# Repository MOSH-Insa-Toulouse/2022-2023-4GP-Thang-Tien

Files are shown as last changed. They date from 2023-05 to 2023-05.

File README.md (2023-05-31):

# 2022-2023-4GP-Thang-Tien

# 1. Contexte et objectifs du projet
- [x] Réaliser une jauge de contrainte low-tech à base de graphite: [Pencil Drawn Strain Gauges and Chemiresistors on Paper](https://www.researchgate.net/publication/259846610_Pencil_Drawn_Strain_Gauges_and_Chemiresistors_on_Paper)
- [x] Concevoir un shield Arduino contenant l'amplificateur du capteur et les composants électroniques annexes (émetteur/récepteur Bluetooth, encodeur rotatif et écran OLED)
- [x] Réaliser une application mobile connectée à l'émetteur Bluetooth du capteur sous APP MIT INVENTOR 
- [x] Effectuer une évaluation du capteur sur un banc d'essai afin de produire une fiche technique et de comparer la technologie utilisée avec celle d'un autre capteur commercial similaire

# 2. Capteur de contrainte
> Notre capteur de contrainte utilise une jauge en papier équipée d'un circuit résistif en graphite, offrant l'avantage d'être facile à installer à moindre coût.
> La théorie de la percolation est exploitée dans ce capteur low-tech, qui est composé de nanoparticules de graphite formant des feuillets. Le réseau percolé caractéristique de la fine couche de graphite déposée sur la feuille de papier permet le transport des électrons entre les nanoparticules par l'effet tunnel. La déformation de la jauge en tension ou en compression entraîne une variation de la résistance de la couche de graphite, ce qui permet de mesurer la contrainte et la déformation appliquées.
> Le fonctionnement de notre jauge de contrainte repose sur la variation de la résistance du circuit résistif en fonction de sa déformation. Elle est alimentée par une tension régulée de 5V fournie par une carte Arduino UNO. Le courant circulant dans la jauge est mesuré pour fournir le signal du capteur, qui doit ensuite être amplifié et filtré.
  ## 2.1. Circuit amplificateur
  > La conductance des jauges en graphite que nous utilisons est très faible (de l'ordre de la dizaine de nS) et est alimentée par une tension continue de 5V. Le circuit amplificateur du capteur doit alors être en mesure d'extraire l'information d'un signal en courant de très faible intensité.
 > Dans ce projet, nous avons décidé d'utiliser un montage transimpédance constitué d'un amplificateur opérationnel (AOP) pour fournir un signal en tension suffisant au convertisseur analogique-numérique (ADC) d'une carte Arduino UNO.
 
 >   Notre jauge de contrainte est composée d'une seule résistance en série. De ce fait, notre signal est sensible aux dérives en tension de l'amplificateur. Notre AOP doit donc avoir un offset de tension en entrée très faible de manière à ce qu'il ne puisse fausser le signal fourni à l'ADC. Cela restreint notre choix d'amplificateur opérationnel. Nos jauges de contrainte en graphite ont une conductivité aux alentours de 10 nS. La jauge étant alimentée par 5V, nous nous attendons à avoir un signal en courant de l'ordre de 50 nA. En shuntant ce courant par une résistance de 100 kΩ, le signal en tension fourni à l'AOP est de 5 mV. À titre de comparaison, l'amplificateur [LM741](https://www.ti.com/lit/ds/symlink/lm741.pdf) présente un offset en entrée typique de 1 mV, et pouvant atteindre 5 mV. Ce composant n'est donc pas adapté pour notre utilisation. Ainsi notre amplificateur doit spécifiquement présenter un offset en entrée faible. Pour cette raison, nous utilisons le [LTC1050](https://www.analog.com/media/en/technical-documentation/data-sheets/1050fb.pdf), pour sa tension de dérive de 5 µV, soit 1000 fois plus faible que notre signal nominal de 5 mV.
 
 >   À partir de cet AOP, nous élaborons l'architecture du circuit amplificateur (cf. [Figure 1a](analog_circuit_images/analog_circuit.JPG)). Ce dernier dispose de trois étages de filtrage:
 >   - à l'entrée, un filtre passe-bas (R1C1) de fréquence de coupure de 16 Hz permet de filtrer les bruits en courant sur le signal d'entrée
 >   - un autre filtre passe bas de 1.6 Hz (R3C2) couplé à l'AOP permet de filtrer la composante du bruit à 50 Hz provenant du réseau électrique
 >   - à la sortie de l'amplificateur, un dernier filtre (R4C4) de 1.6 kHz permet de traiter les bruits dus à l'échantillonage de l'ADC

 >   La capacité C3 sert à filtrer les irrégularités de la tension d'alimentation de l'amplificateur. La résistance R2 sert à calibrer l'amplificateur sur le domaine de tension souhaité, qui est celui de l'ADC du micro-contrôleur. Lors de la phase de prototypage du circuit, nous avons utilisé un potentiomètre digital à la place de cette résistance pour trouver sa valeur. Enfin, la résistance R5 protège l'AOP contre les décharges électrostatiques et constitue un filtre RC avec la capacité C1 pour les bruits en tension.

 > <div class="row" align="center">
   > 
   > </div>
**Figure 1a - Circuit amplificateur transimpédance. La résistance *Rsensor* représente la jauge de contrainte.**
 
 > <div class="row" align="center">
   > 
   > </div>
**Figure 1b - Simulation AC du circuit amplificateur. Les fréquences de coupure à 1.6 Hz, 16 Hz et 1.6 kHz des trois filtres en cascade sont visibles. Cette simulation permet de vérifier le fonctionnement en fréquence de notre circuit.**

> Pour vérifier le fonctionnement normal du circuit sur LTSpice, nous simulons la déformation de la jauge par un pulse de tension en entrée (Figure 2). Ce pulse de tension génère une variation du courant en entrée de l'AOP. Virtuellement, cela représente la variation de conductance de la jauge due à sa déformation. Pour cette simulation, nous faisons varier la conductance de 5 nS à 20 nS, ce qui correspond à l'ordre de grandeur des jauges resistives utilisées. Ce faisant, nous balayons à peu près tout l'intervalle de signaux d'entrée possibles:

 > <div class="row" align="center">
   > 
   > </div>
**Figure 2 - Simulation du fonctionnement du circuit amplificateur. Un pulse de tension permet de modéliser la déformation de la jauge et la variation du signal en courant.**
 
 > <div class="row" align="center">
   > 
   > </div>
**Figure 3: Résultats de la simulation. En bleu, le signal en courant fourni par la jauge et en vert la tension de sortie de l'AOP.**

> En prenant en compte la plage de conductance considérée, le signal de sortie varie d'environ 240 mV à 1,05 V, ce qui ne sature pas l'ADC. L'amplitude crête-à-crête du bruit à 50 Hz est de 14 mV RMS. Ainsi, ce signal est détectable par l'ADC qui a une sensibilité d'environ 5 mV. Le rapport signal sur bruit est de 25,6 dB pour la conductance la plus faible et de 37,2 dB pour la conductance la plus élevée. Bien que notre signal dans cette simulation ne soit pas considéré comme optimal en termes d'instrumentation (rapport signal sur bruit inférieur à 40 dB), il est important de noter que plus le signal de sortie est élevé (c'est-à-dire plus la conductance est élevée), plus le bruit à 50 Hz est atténué par le signal. Cela signifie que des mesures plus fiables et précises peuvent être obtenues en utilisant des jauges de contrainte de résistance relativement faibles (environ 50 MΩ ou moins). Pour avoir une plus grande flexibilité quant aux conductances des jauges utilisées, il aurait été possible d'intégrer directement sur le PCB un potentiomètre numérique en remplacement de R2. Cela aurait permis, après une étape de calibration, d'adapter le signal de sortie à la jauge résistive utilisée afin d'obtenir un signal optimal. Cependant, si nous limitons l'utilisation de jauges présentant des conductances suffisamment élevées, nous obtenons un signal tout à fait acceptable.

  ## 2.2. Intégration Arduino
   > <div class="row" align="center">
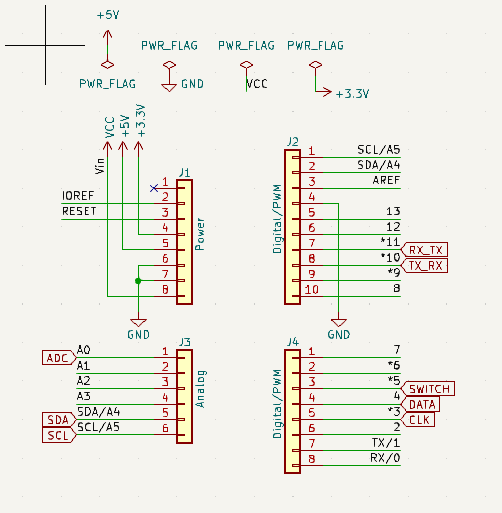
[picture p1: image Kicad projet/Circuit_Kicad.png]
   > 
   > </div>
  
   > <div class="row" align="center">
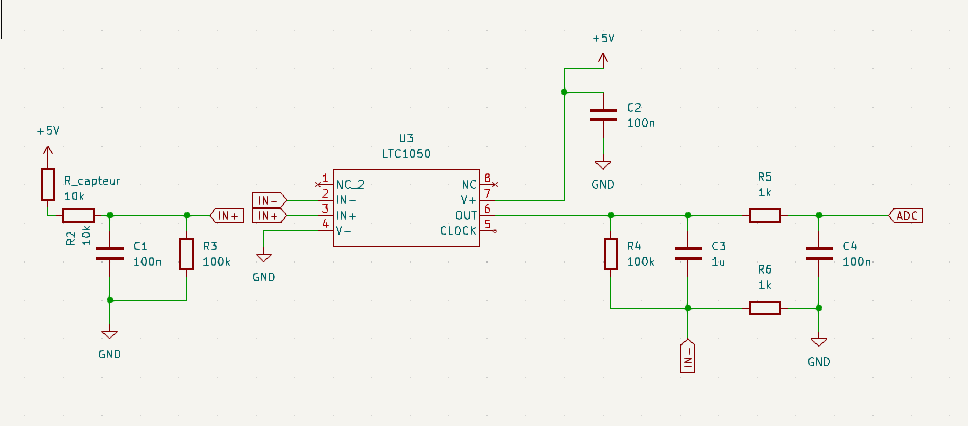
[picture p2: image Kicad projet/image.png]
   > 
   > </div>

   > <div class="row" align="center">
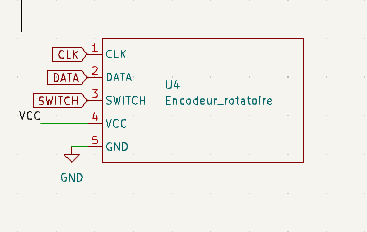
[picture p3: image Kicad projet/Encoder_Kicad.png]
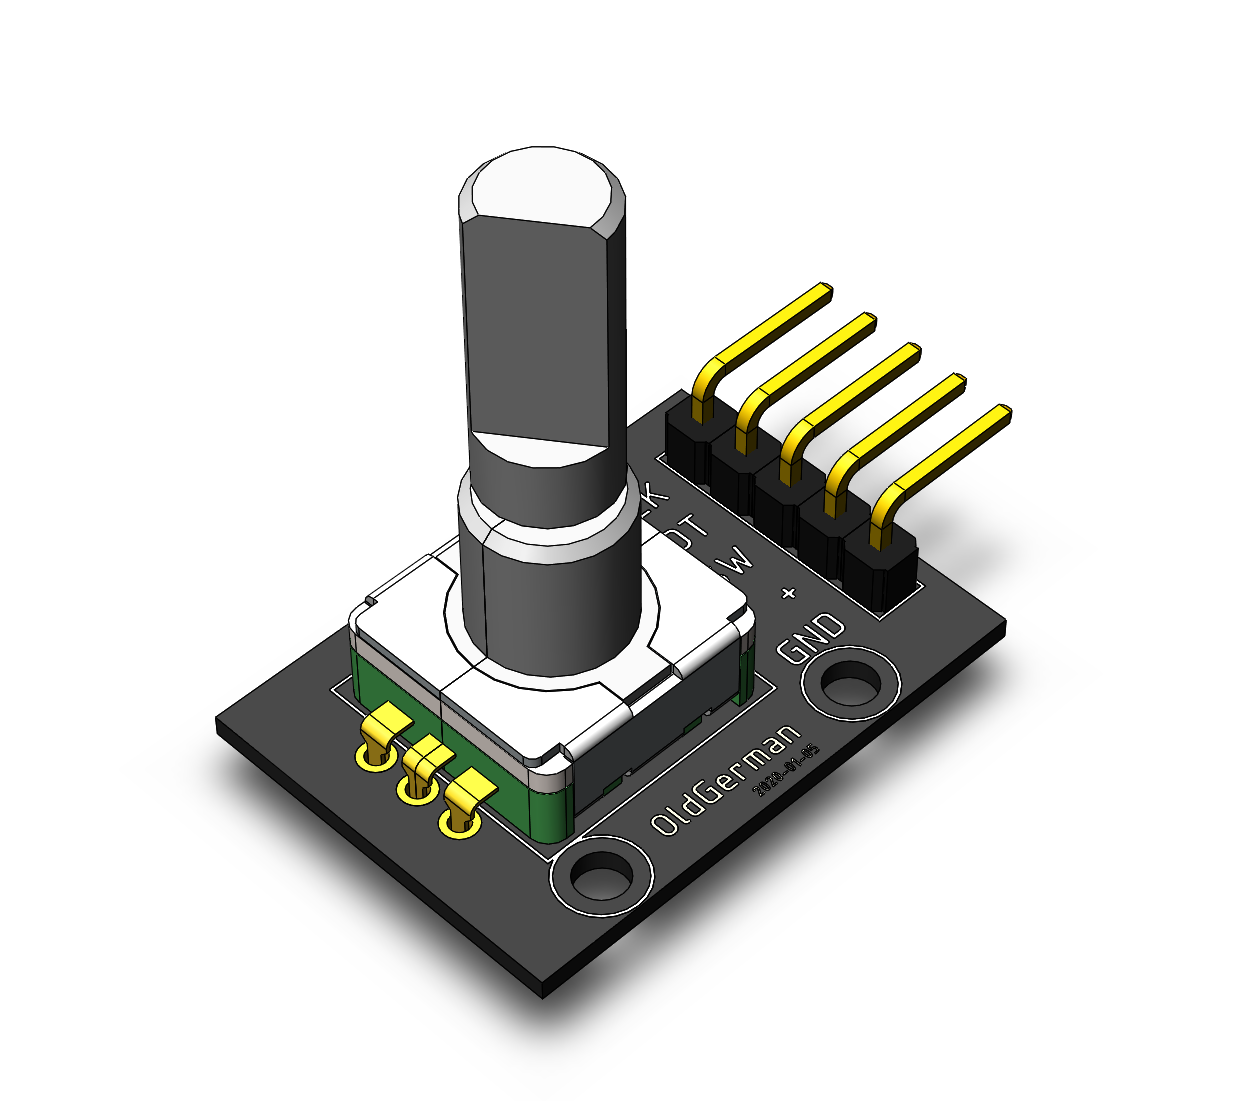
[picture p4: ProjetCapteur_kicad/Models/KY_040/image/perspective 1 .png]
   >  
   > </div>
  
   > <div class="row" align="center">
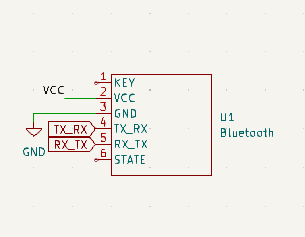
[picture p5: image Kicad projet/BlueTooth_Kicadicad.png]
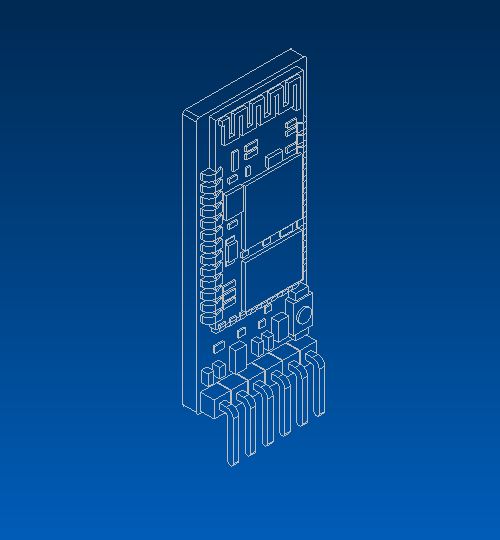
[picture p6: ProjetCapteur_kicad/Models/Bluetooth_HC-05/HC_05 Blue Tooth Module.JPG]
   >  
   > </div>
   
   > <div class="row" align="center">
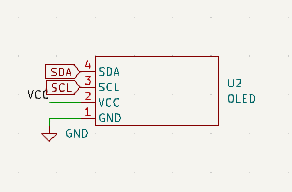
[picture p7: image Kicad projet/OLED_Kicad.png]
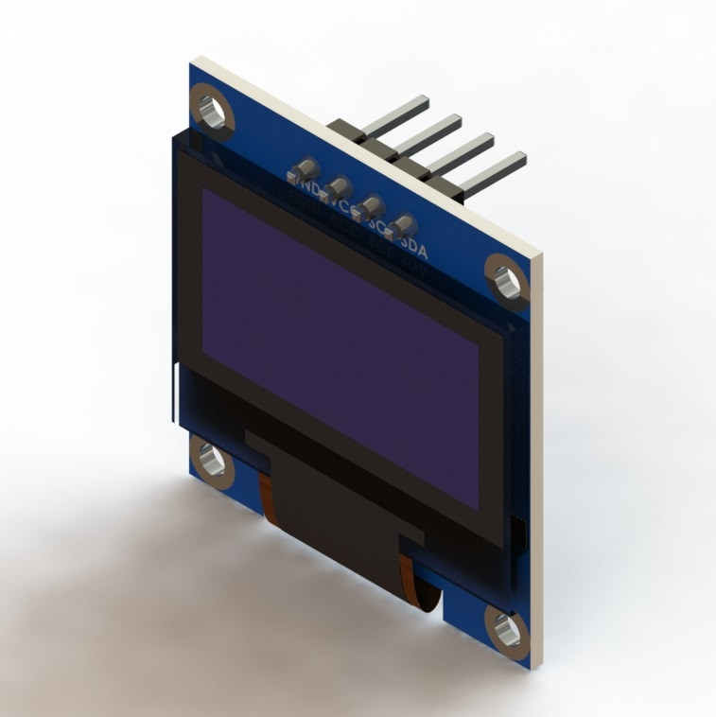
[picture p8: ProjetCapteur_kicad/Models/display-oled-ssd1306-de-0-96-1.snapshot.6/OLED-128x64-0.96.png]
   >  
   > </div>
  
   > <div class="row" align="center">
   >  
   > </div>
 
   **Figure 4 - Design du PCB.**

   > <div class="row" align="center">
   > 
   > </div>

   **Figure 5 - Circuit intergré des composants.** 

# 3. Programme Arduino
> Le programme Arduino permet de calculer la valeur de la résistance du capteur à partir de la valeur de tension mesurée par l'ADC de la carte. Cette mesure résistive est ensuite envoyée à l'application mobile via Bluetooth si cela est requis sur l'application. L'encodeur rotatif permet d'activer un menu sur l'OLED de choix d'affichage sur celui-ci : soit on affiche la valeur de la résistance, soit on affiche la valeur de la tension. On peut également choisir d'afficher une image ou les crédits (défilants).
> 
> A la mise en route du programme, une animation d'initialisation apparaît sur l'écran. Après cela, on a directement accès à la valeur résistive mesurée par le capteur. En tournant l'encodeur rotatoire, on peut rentrer dans le menu et sélectionner l'affichage de son choix toujours grâce à la rotation de l'encodeur. Ensuite, on valide le choix en faisant une pression sur l'encodeur.

# 4. Application mobile
> Dans le cadre de ce projet, nous avons programmé sur MIT APP INVENTOR, l'application mobile connectée au module Bluetooth du capteur. Cette dernière est constituée d'une seule activité sur laquelle il est possible d'acquérir les données du capteur en temps réel et de les tracer sur un graphique dynamique.
 > <div class="column" align="center">
 > 
 > </div>
 **Figure 6 - page d'accueil de la dernière version de l'application mobile. Cette capture d'écran a été prise pendant le fonctionnement du capteur.**
 
> On programme des blocks de fonction pour connecter Module Bluetooth HC05 et tracer le variation de resistance en temps.
 > <div class="column" align="center">
 > 
  **Figure 7 - Blocks Connection Bluetooth .**
 > 
 > 
 > 
   **Figure 7 - Blocks Initialiser programme et mapping valeur pour le graphe.**
 > 
 > 
  **Figure 7 - Blocks tracer le graphe.**
 > </div>

 > Pour la connection Bluetooth, le smartphone doit être appareillé au module du capteur avant de pouvoir se connecter via l'application mobile. L'application ne permet pas de choisir à quel module se connecter. En réalité, l'application est liée à un module bluetooth en particulier (celui fourni avec le capteur) et lui seul pourra être connecté au smartphone pour la transmission de données. Une piste d'amélioration consiste à afficher la liste des dispositifs appareillés pour se connecter au module souhaité. Nous n'avons cependant pas pu implémenter cette fonctionnalité par manque de temps.

 > N.B: le fichier .apk de l'application mobile est situé dans le répertoire suivant: [ici](https://github.com/MOSH-Insa-Toulouse/2022-2023-4GP-Thang-Tien/blob/0f889ce377105a8e069ff56407e032ddfc5c72b9/application%20Android/APP_PROJET_CAPTEUR.apk)
# 5. Mesures : Banc de test, datasheet et discussions
  ## 5.1. Banc de test
   > <div class="column" align="center">
 > 
 > </div>
  Nous utilisons ce banc de test composé de 7 demi cylindres de différents diamètres allant de 2 à 5 cm avec un pas de 0,5 cm. Nous posons le capteur sur chacun des cylindres et appliquons donc une déformation sur celui-ci. Cette déformation se retrouve avec la formule ci-dessous :
            $$\epsilon = \frac{e}{2r}$$
 La déformation ε dépend de l'épaisseur (**e**) de la feuille du capteur (nous avons prit pour ça 0.16mm qui est le grammage de feuille 140g/m²) et du rayon de courbure des cercles (**r**) donc le rayon de chaque demi cylindre. Nous avons réalisé les mesures en compression et en tension pour chacun de nos capteurs. 
  ## 5.2. Mesures et résultats
  
  On realise la test sur le capteur graphite de HB, 2H sous même tension entrée. 
  > <div class="column" align="center">
 > 
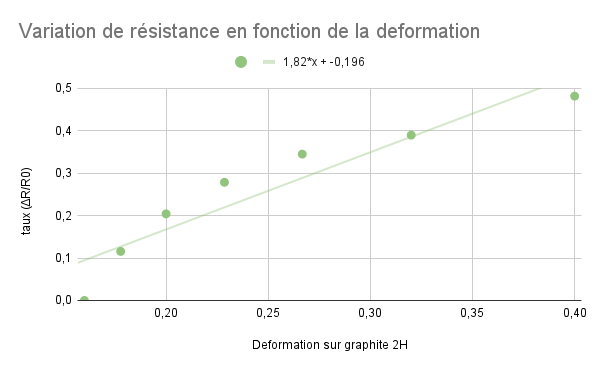
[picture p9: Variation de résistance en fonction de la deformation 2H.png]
 > 
 > </div>
 
  Le pente de courbe de HB est inférieur à celui de 2H, correspondant au taux ΔR/R0 inférieur. Les mines les plus dures contiennent une grande quantité de liants argileux et donc moins de graphite, tandis que les mines plus tendres déposent une plus grande quantité de graphite sur le papier. Dans notre cas, cette différence de concentration de graphite sur le capteur influence sa résistance. C'est pourquoi les courbes associées aux mines HB présentent des valeurs de résistance (ΔR/R0) inférieures à celles de la mine 2H, qui est plus dure. 
  ## 5.3. Datasheet
  La fiche technique est disponible [ici](https://github.com/MOSH-Insa-Toulouse/2022-2023-4GP-Thang-Tien/blob/main/Datasheet/Datasheet_graphite_sensor.pdf).

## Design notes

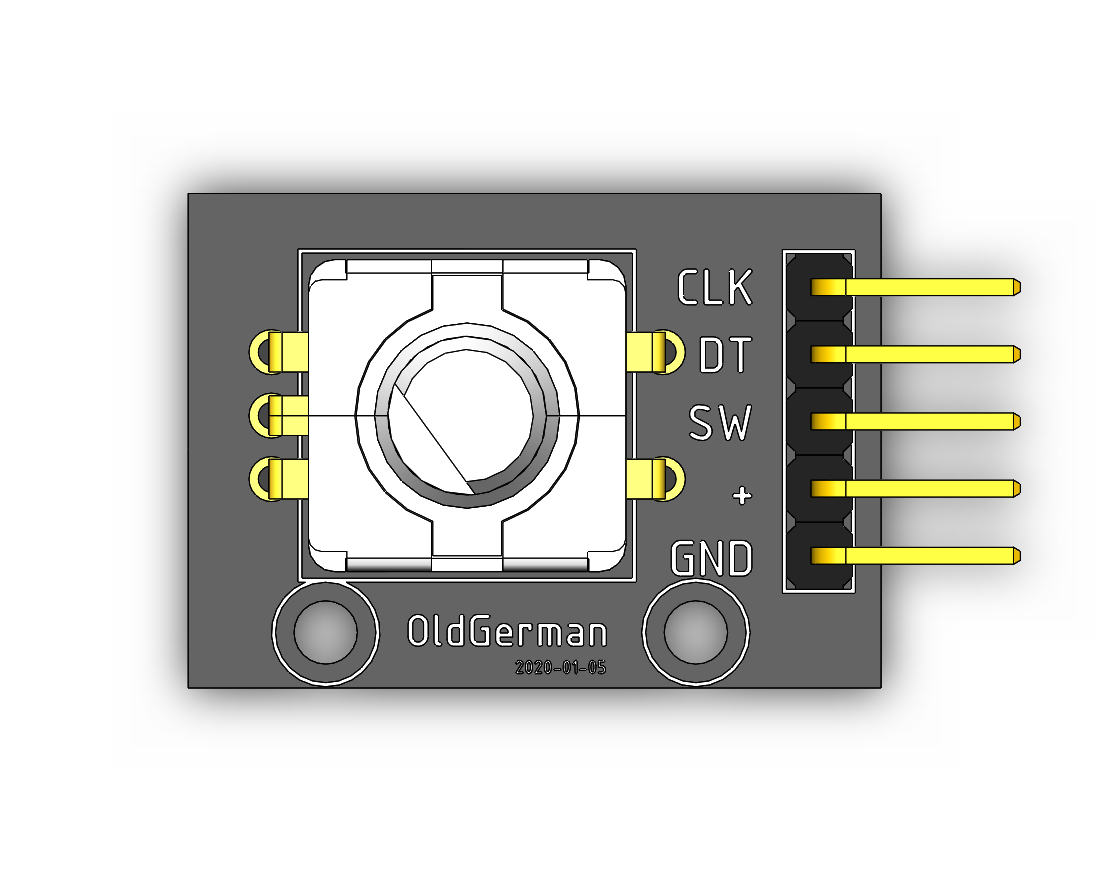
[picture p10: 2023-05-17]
ProjetCapteur_kicad/Models/KY_040/image/top.png

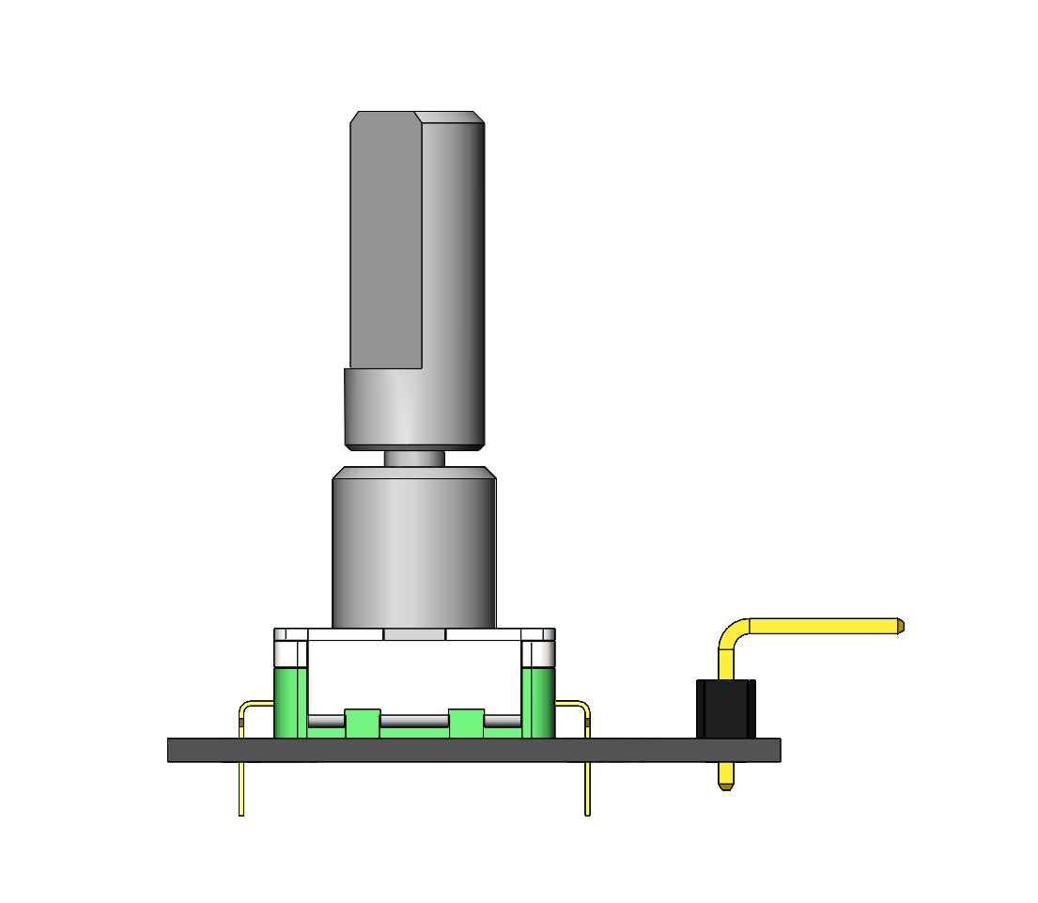
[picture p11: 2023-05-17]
ProjetCapteur_kicad/Models/KY_040/image/left.png

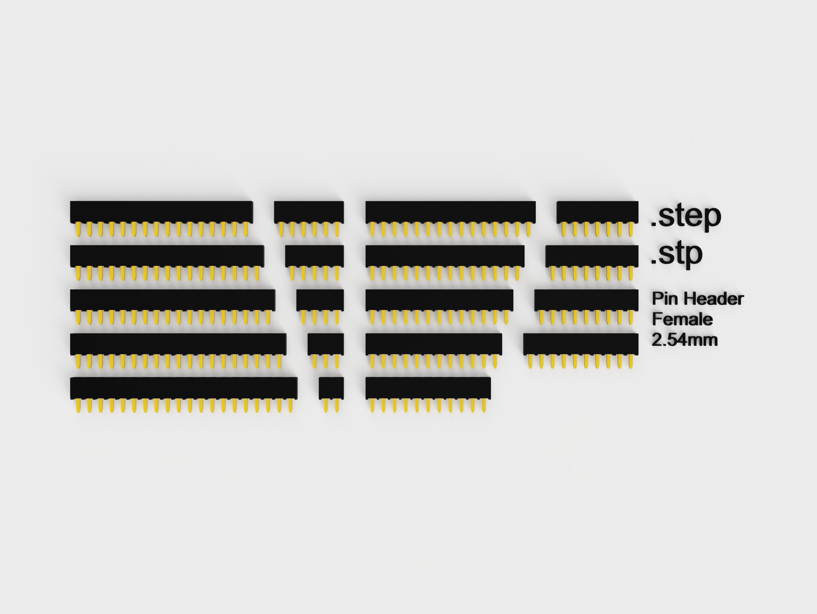
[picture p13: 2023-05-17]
ProjetCapteur_kicad/Models/pin_header/Pin_Header-Female-2.54mm_V3.png

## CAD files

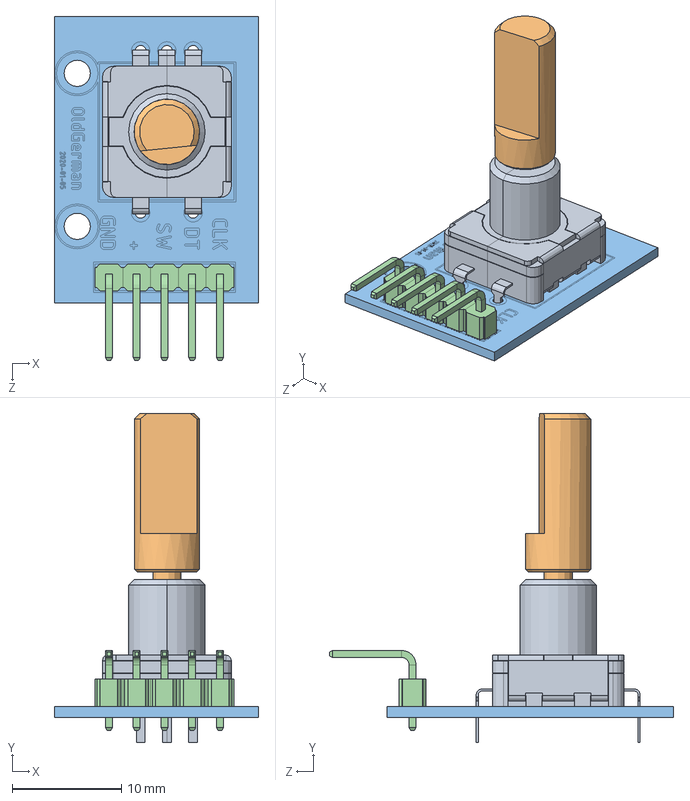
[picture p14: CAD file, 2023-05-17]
ProjetCapteur_kicad/Models/KY_040/sw2017 model/KY-040 Rotary Encoder.SLDASM
18.7 x 30.1 x 31.5 mm
Rotary Encoder
D-handle
pcb
2.54 5PIN 90

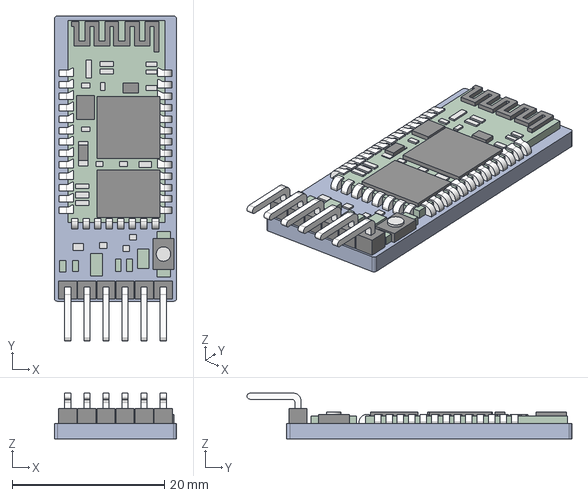
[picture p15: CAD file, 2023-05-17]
ProjetCapteur_kicad/Models/Bluetooth_HC-05/HC_05 Blue Tooth Module.stp
16.1 x 42.7 x 6.00 mm

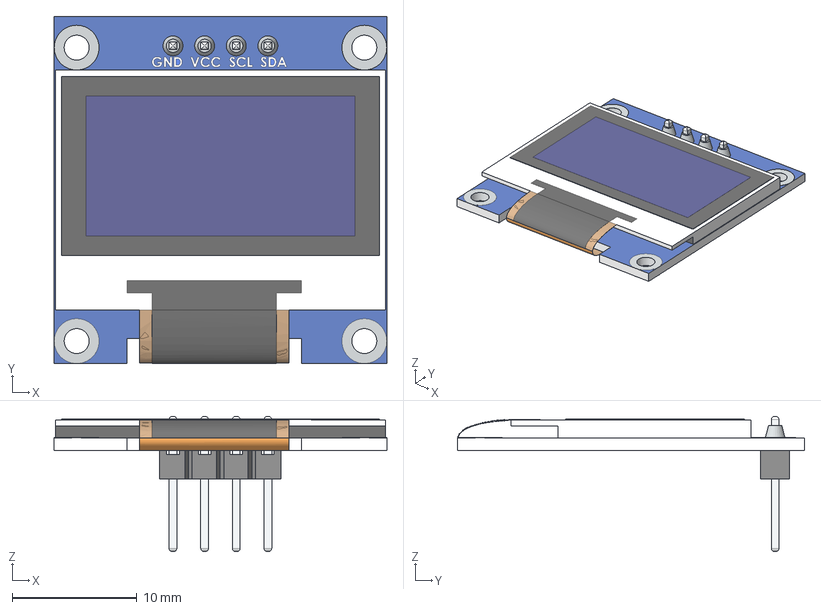
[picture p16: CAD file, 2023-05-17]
ProjetCapteur_kicad/Models/display-oled-ssd1306-de-0-96-1.snapshot.6/OLED-128x64-0.96.step
26.7 x 27.9 x 10.8 mm

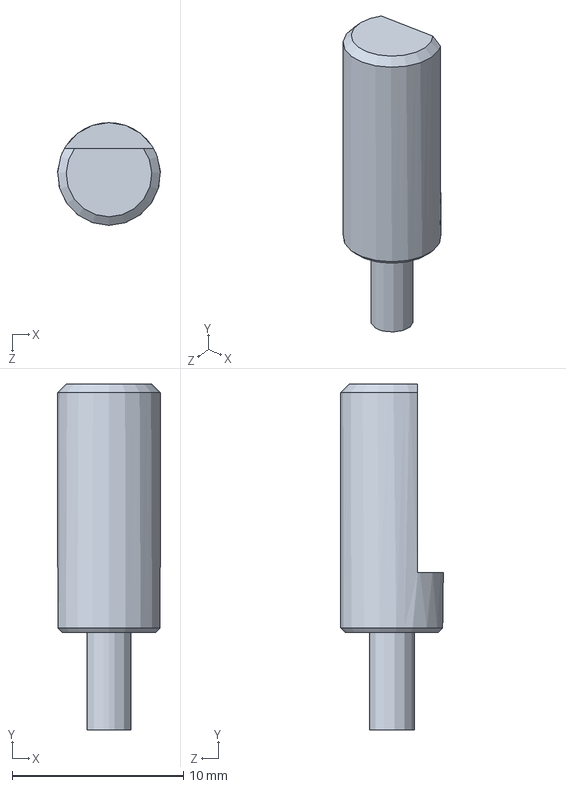
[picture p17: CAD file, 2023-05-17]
ProjetCapteur_kicad/Models/KY_040/sw2017 model/D-handle.SLDPRT
6.00 x 20.2 x 6.00 mm

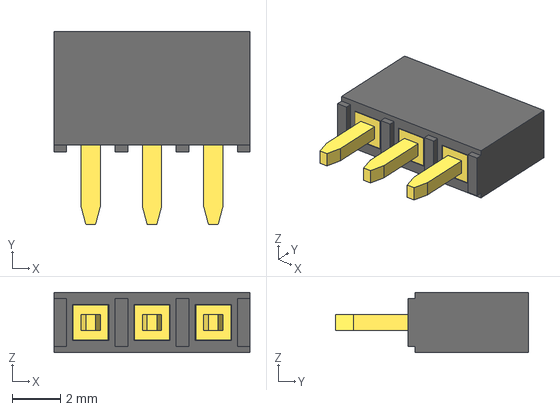
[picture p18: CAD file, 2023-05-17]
ProjetCapteur_kicad/Models/pin_header/3-Pin Header - Female - 2.54mm.step
8.12 x 8.00 x 2.50 mm

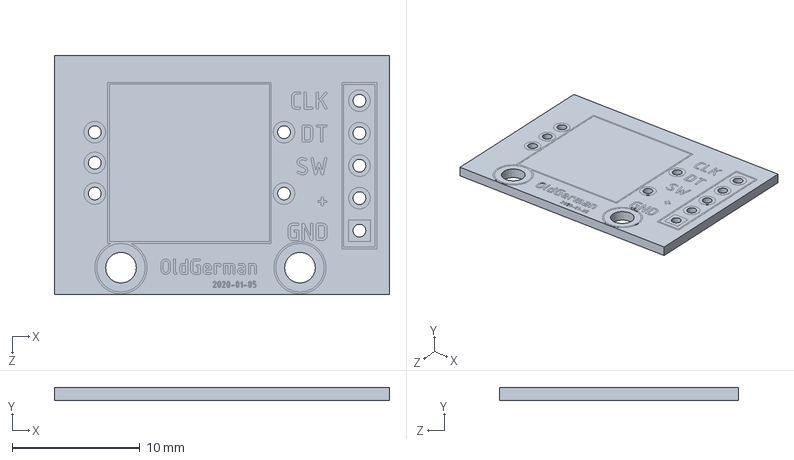
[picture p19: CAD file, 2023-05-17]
ProjetCapteur_kicad/Models/KY_040/sw2017 model/pcb.SLDPRT
26.2 x 1.02 x 18.7 mm

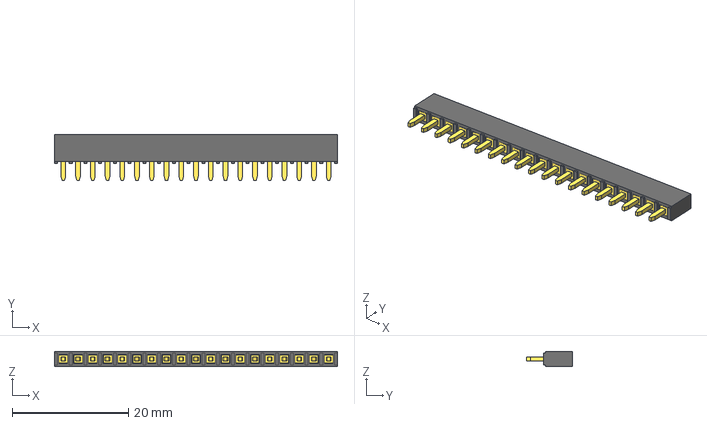
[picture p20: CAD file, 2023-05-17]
ProjetCapteur_kicad/Models/pin_header/19-Pin Header - Female - 2.54mm.step
48.8 x 8.00 x 2.50 mm

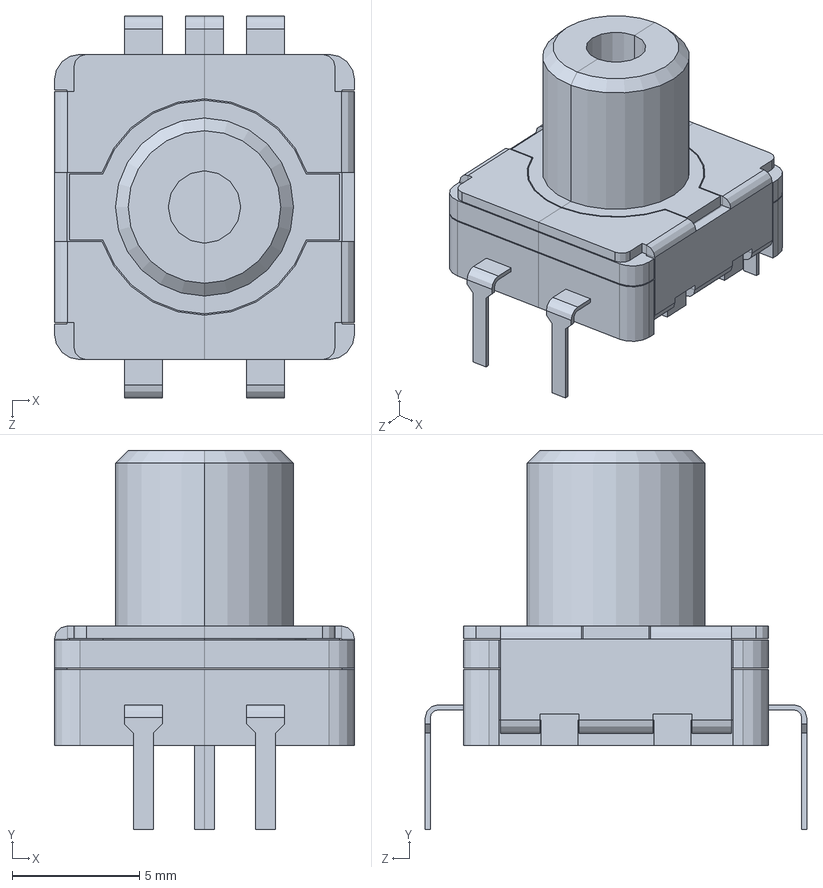
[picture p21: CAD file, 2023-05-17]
ProjetCapteur_kicad/Models/KY_040/sw2017 model/Rotary Encoder.SLDPRT
11.8 x 14.9 x 15.0 mm

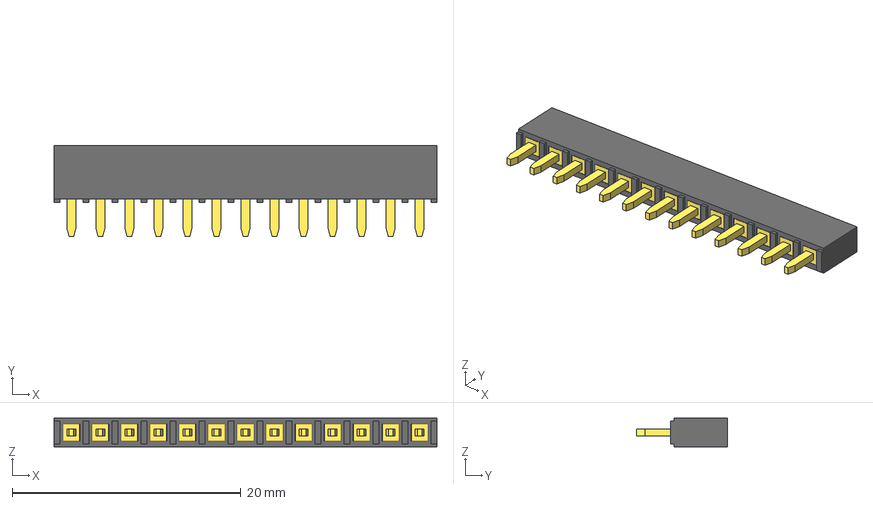
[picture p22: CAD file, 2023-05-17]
ProjetCapteur_kicad/Models/pin_header/13-Pin Header - Female - 2.54mm.step
33.5 x 8.00 x 2.50 mm

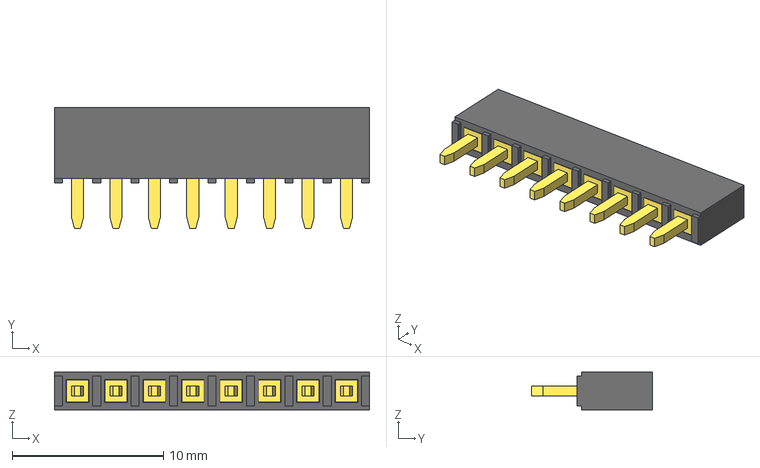
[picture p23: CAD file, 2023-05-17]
ProjetCapteur_kicad/Models/pin_header/8-Pin Header - Female - 2.54mm.step
20.8 x 8.00 x 2.50 mm

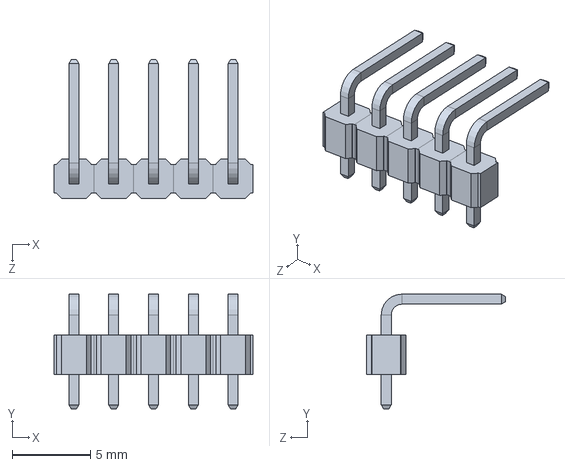
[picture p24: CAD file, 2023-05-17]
ProjetCapteur_kicad/Models/KY_040/sw2017 model/2.54 5PIN 90.SLDPRT
12.7 x 7.32 x 8.85 mm

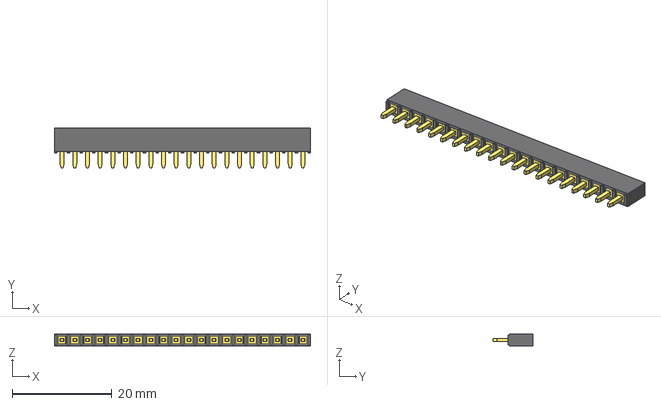
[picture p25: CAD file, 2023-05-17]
ProjetCapteur_kicad/Models/pin_header/20-Pin Header - Female - 2.54mm.step
51.3 x 8.00 x 2.50 mm

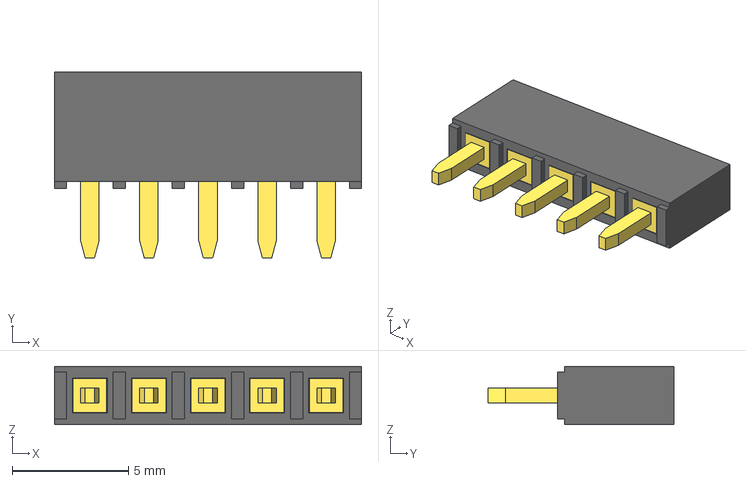
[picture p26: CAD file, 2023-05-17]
ProjetCapteur_kicad/Models/pin_header/5-Pin Header - Female - 2.54mm.step
13.2 x 8.00 x 2.50 mm

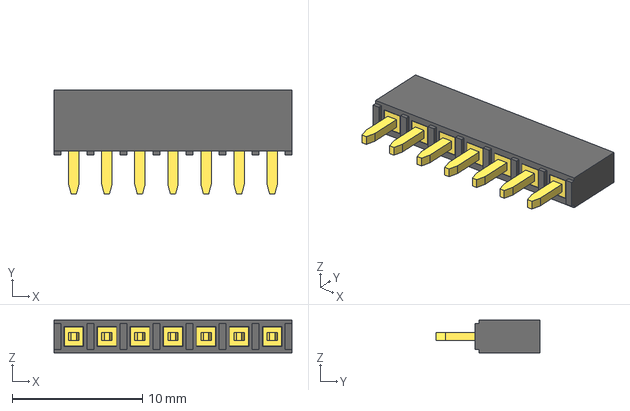
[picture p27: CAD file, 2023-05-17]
ProjetCapteur_kicad/Models/pin_header/7-Pin Header - Female - 2.54mm.step
18.3 x 8.00 x 2.50 mm

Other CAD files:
ProjetCapteur_kicad/Models/KY_040/KY-040 Rotary Encoder.STEP
ProjetCapteur_kicad/Models/pin_header/10-Pin Header - Female - 2.54mm.step
ProjetCapteur_kicad/Models/pin_header/16-Pin Header - Female - 2.54mm.step
ProjetCapteur_kicad/Models/pin_header/9-Pin Header - Female - 2.54mm.step
ProjetCapteur_kicad/Models/Bluetooth_HC-05/HC_05 Blue Tooth Module.ipt
ProjetCapteur_kicad/Models/pin_header/11-Pin Header - Female - 2.54mm.step
ProjetCapteur_kicad/Models/pin_header/12-Pin Header - Female - 2.54mm.step
ProjetCapteur_kicad/Models/pin_header/14-Pin Header - Female - 2.54mm.step
ProjetCapteur_kicad/Models/pin_header/15-Pin Header - Female - 2.54mm.step
ProjetCapteur_kicad/Models/pin_header/17-Pin Header - Female - 2.54mm.step
ProjetCapteur_kicad/Models/pin_header/18-Pin Header - Female - 2.54mm.step
ProjetCapteur_kicad/Models/pin_header/2-Pin Header - Female - 2.54mm.step
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

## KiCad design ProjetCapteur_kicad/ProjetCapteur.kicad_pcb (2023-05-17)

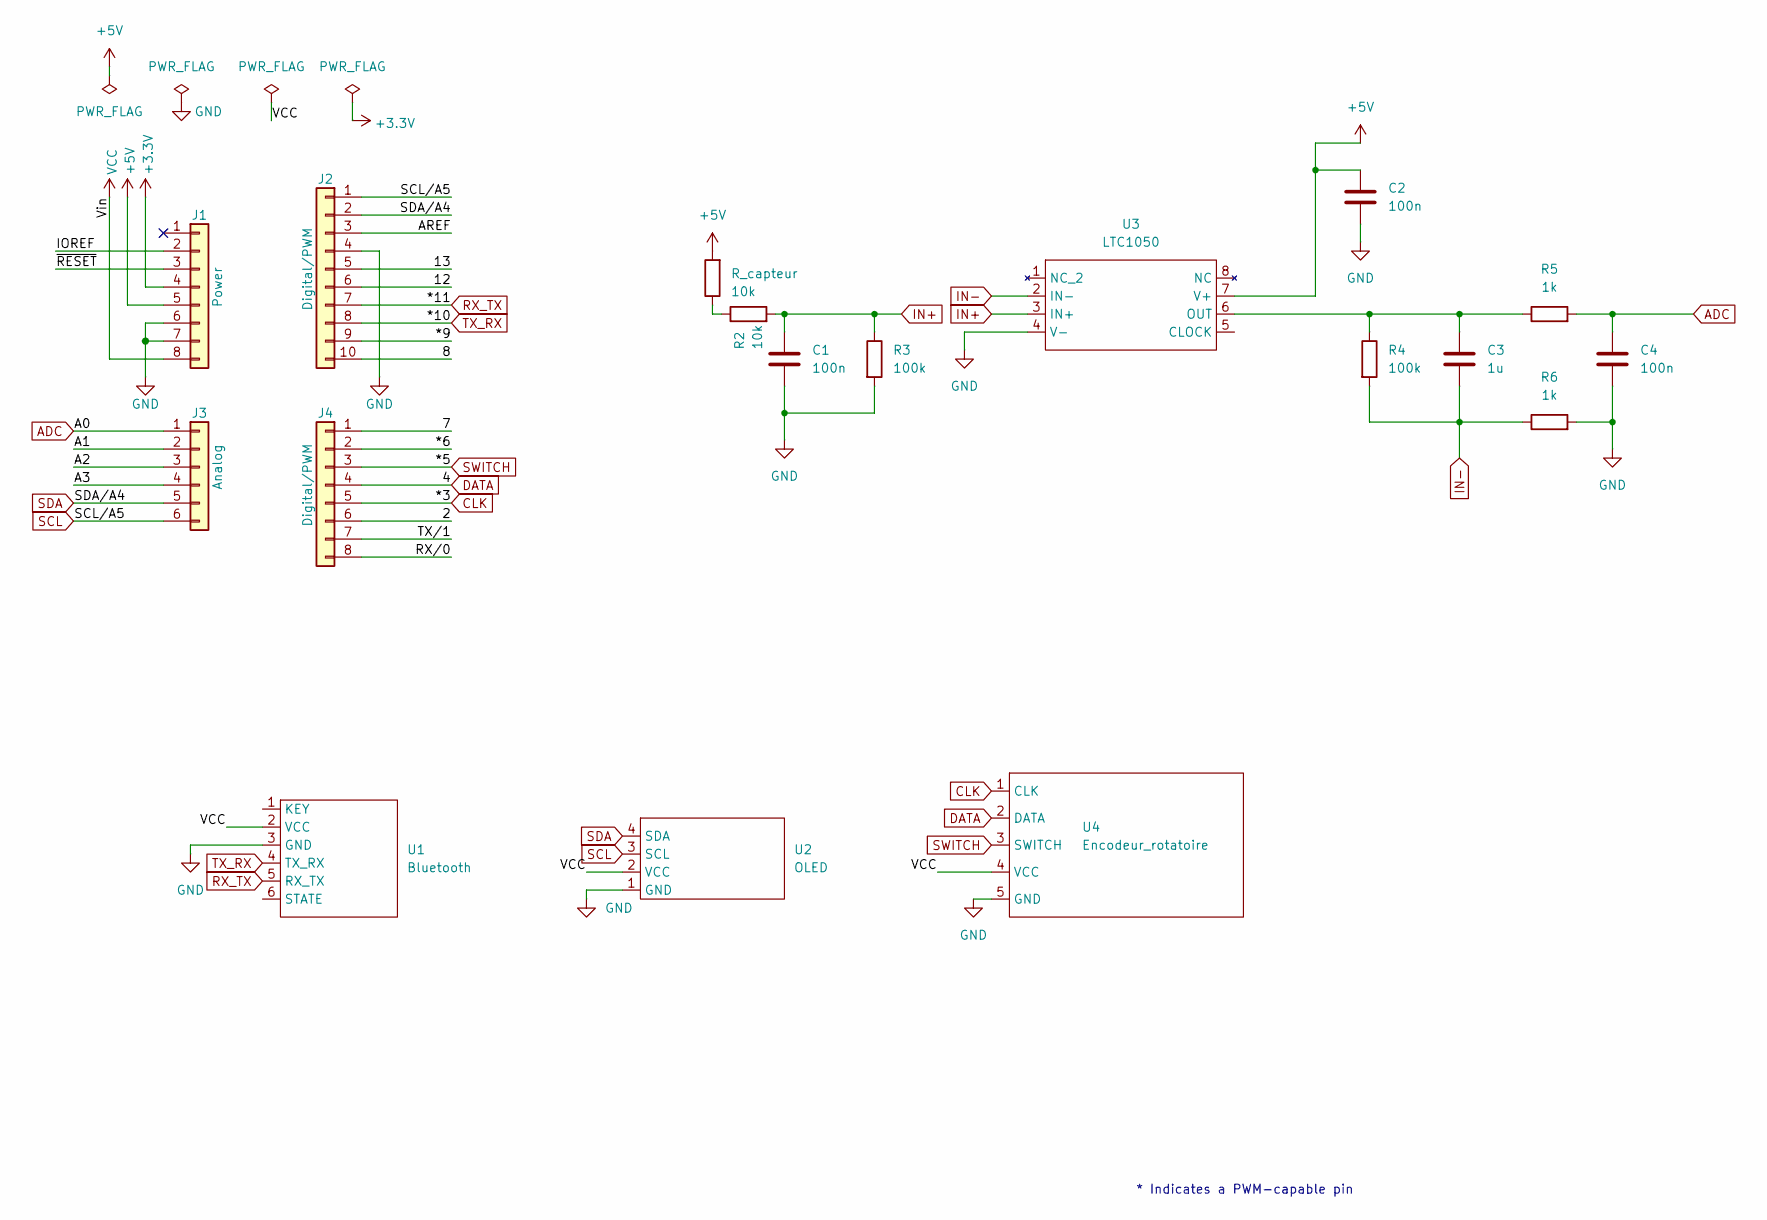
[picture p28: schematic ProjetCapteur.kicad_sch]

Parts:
C1, C2, C4: 100n; C_Disc_D5.0mm_W2.5mm_P5.00mm
C3: 1u; C_Rect_L9.0mm_W5.1mm_P7.50mm_MKT
J1: Power; PinSocket_1x08_P2.54mm_Vertical
J2: Digital/PWM; PinSocket_1x10_P2.54mm_Vertical
J3: Analog; PinSocket_1x06_P2.54mm_Vertical
J4: Digital/PWM; PinSocket_1x08_P2.54mm_Vertical
R2: 10k; R_Axial_DIN0207_L6.3mm_D2.5mm_P7.62mm_Horizontal
R3, R4: 100k; R_Axial_DIN0207_L6.3mm_D2.5mm_P7.62mm_Horizontal
R5, R6: 1k; R_Axial_DIN0207_L6.3mm_D2.5mm_P7.62mm_Horizontal
R_capteur: 10k; R_Axial_DIN0207_L6.3mm_D2.5mm_P7.62mm_Horizontal
U1: Bluetooth; BLUETOOTH_HC05
U2: OLED
U3: LTC1050
U4: Encodeur_rotatoire; KY_040

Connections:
+3V3: J1.4
+5V: C2.1, J1.5, R_capteur.2, U3.7 (V+); also elsewhere on the board
/2: J4.6
/7: J4.1
/8: J2.10
/12: J2.6
/13: J2.5
/*6: J4.2
/*9: J2.9
/A1: J3.2
/A2: J3.3
/A3: J3.4
/AREF: J2.3
/IOREF: J1.2
/RX/0: J4.8
/TX/1: J4.7
/~RESET: J1.3
ADC: C4.1, J3.1, R5.2
CLK: J4.5, U4.1 (CLK)
DATA: J4.4, U4.2 (DATA)
GND: C1.2, C2.2, C4.2, J1.6, J1.7, J2.4, R3.2, R6.2, U1.3 (GND), U2.1 (GND), U3.4 (V-), U4.5 (GND)
IN+: C1.1, R2.2, R3.1, U3.3 (IN+)
IN-: C3.2, R4.2, R6.1, U3.2 (IN-)
unnamed: C3.1, R4.1, R5.1, U3.6 (OUT)
unnamed 24: R2.1, R_capteur.1; also elsewhere on the board
RX_TX: J2.7, U1.5 (RX_TX)
SCL: J2.1, J3.6, U2.3 (SCL)
SDA: J2.2, J3.5, U2.4 (SDA)
SWITCH: J4.3, U4.3 (SWITCH)
TX_RX: J2.8, U1.4 (TX_RX)
VCC: J1.8, U1.2 (VCC), U2.2 (VCC), U4.4 (VCC)

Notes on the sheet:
* Indicates a PWM-capable pin

Board: 2 copper layers, 22 parts (0 on the bottom side), 15 nets, no tracks yet.

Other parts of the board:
MH1, MH2, MH3, MH4: MountingHole_3.2mm
R1: 10k; R_Axial_DIN0207_L6.3mm_D2.5mm_P7.62mm_Horizontal

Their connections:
+5V: R1.2; also elsewhere on the board
unnamed 24: R1.1; also elsewhere on the board

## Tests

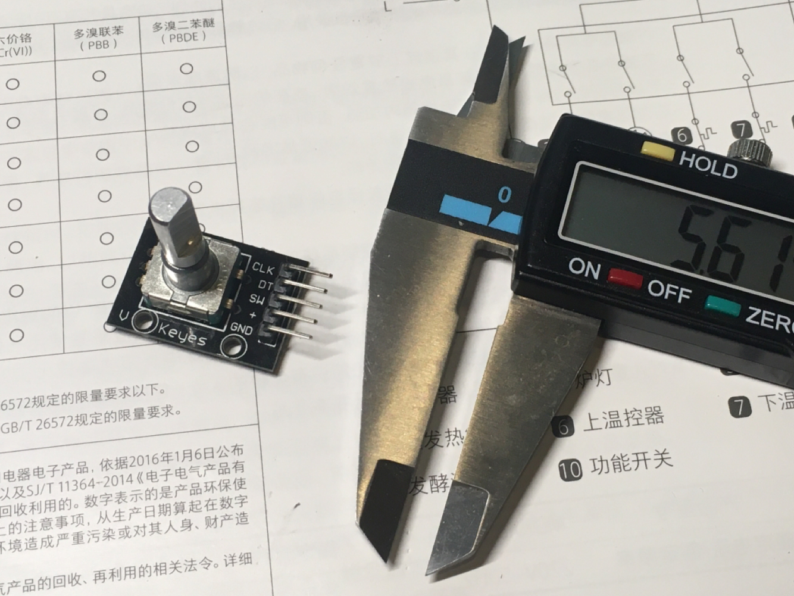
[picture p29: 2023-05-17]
ProjetCapteur_kicad/Models/KY_040/image/Measured by hand.png
